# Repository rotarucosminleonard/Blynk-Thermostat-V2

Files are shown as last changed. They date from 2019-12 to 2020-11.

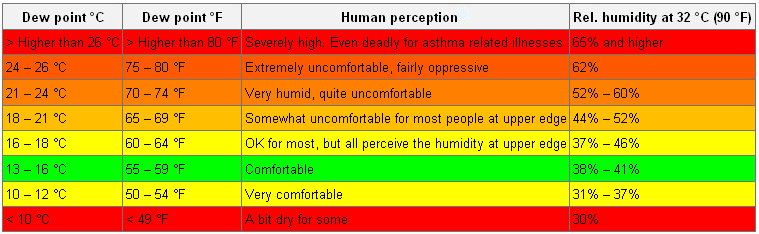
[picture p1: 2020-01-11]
Project files/DewPointComfortRange.jpg

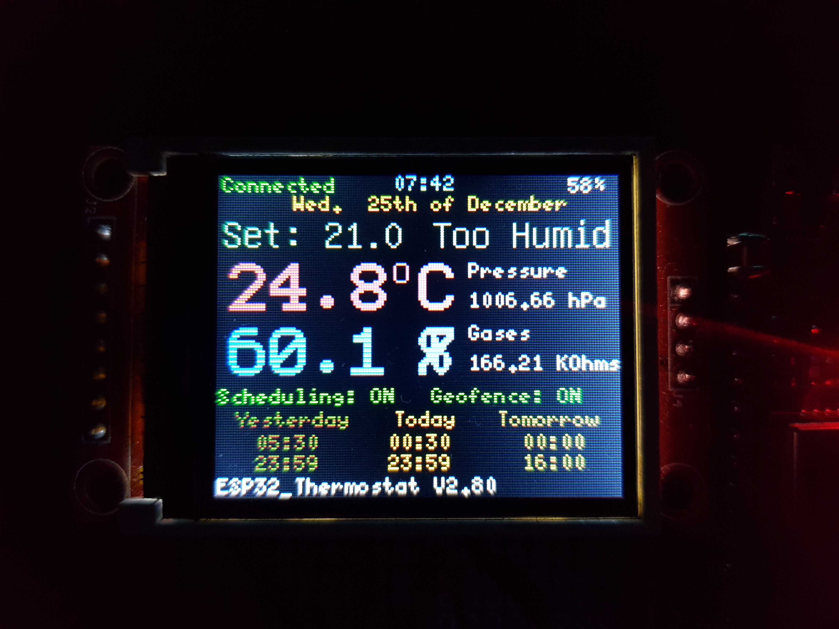
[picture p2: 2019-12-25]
Project files/20191225_074357.jpg

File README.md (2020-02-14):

Warning: This is a work in progress and some of the features are not fully working or not even implemented yet.

The hardware used:
- ESP32 Dev Board
- I2C BME680 for measuring the temp,hum, pressure and air quality - can be easily replaced by the cheaper <a href = "https://www.ebay.co.uk/itm/10DOF-I2C-SPI-MPU9250-BMP280-BME280-Kompass-Barom-for-Arduino-Raspberry-Pi-UK/192137880381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"> BME280(temp,hum,pressure)</a>
- I2C MCP23017
- I2C RTC DS13017z
- SPI ST7735
- <a href ="https://www.ebay.co.uk/itm/Hot-Mini-Wireless-433Mhz-RF-Control-Remote-1527-Learning-Code-Transmitter-Module/232451380539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"> 433 Mhz transmitter</a>
- <a href= "https://www.ebay.co.uk/itm/DC-12V-1-Ch-433MHz-Wireless-Relay-RF-Remote-Control-Switch-Heterodyne-Receiver/292158576954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"> 433 Mhz Relay Module</a> + <a href = "https://www.ebay.co.uk/itm/1-2-5PCS-AC110-220V-to-DC12V-Voltage-Power-Supply-Step-Down-Converter-Module/283386093098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"> Power Module </a>

# Blynk-Thermostat-V2
A smart version of a thermostat that can work and be fully programmed online or offline. It will store the required settings and inputs like temperature setting, operating mode, the time and the time intervals required for scheduling in order to work offline when the connection to the server drops. It will be able to recover it when it's available again. The output command for the heating device can be adjusted for the needs. I am currently using 433mhz modules from eBay for wireless transmission to the heating system and the relay for triggering it. The local time is updated from the server automatically and kept by the RTC module. It can use data from up to remote 3 sensors as temperature reference for heating logic (radiator valves required for this to prevent overheating in some other rooms). 

About the project:
+ The ESP32 works using the Blynk Platform and it displays the data on a LCD colour display (ST7735)  using the UCGLIB library. 
+ The IO pins are extended using the I2c MCP23017 giving the chance to add enough buttons and covering any future hardware improvements. 
+ The offline time kept by an external I2C RTC DS13017z using a library that does not conflict with the Online RTC used by Blynk

Working:
- Scheduling with Geofence Feature
- Heating logic
- Storing the required settings - More tests required
- Timekeeping  - More tests required
- Connection management  - More tests required
- Geofence 
- Wifi Signal
- Local temperature as a refference
- Up to 3 Remote sensors can be used for temperature refference  - More tests required
- Heartbeat for all 3 sensors  - More tests required
- Menu - In progress...

ESP32 (install board)- https://github.com/espressif/arduino-esp32/blob/master/docs/arduino-ide/boards_manager.md

Libraries required:
- Blynk: http://help.blynk.cc/en/articles/512105-how-to-install-blynk-library-for-arduino-ide
- Ucglib: https://github.com/olikraus/ucglib
- Adafruit Unified Sensor: https://github.com/adafruit/Adafruit_Sensor
- Adafruit BME680: https://github.com/adafruit/Adafruit_BME680 ( also recommended BME280) 
- Adafruit MCp23017: https://github.com/adafruit/Adafruit-MCP23017-Arduino-Library
- Arduino Time Library: https://github.com/PaulStoffregen/Time
- Grove - RTC DS1307 : https://github.com/Seeed-Studio/RTC_DS1307

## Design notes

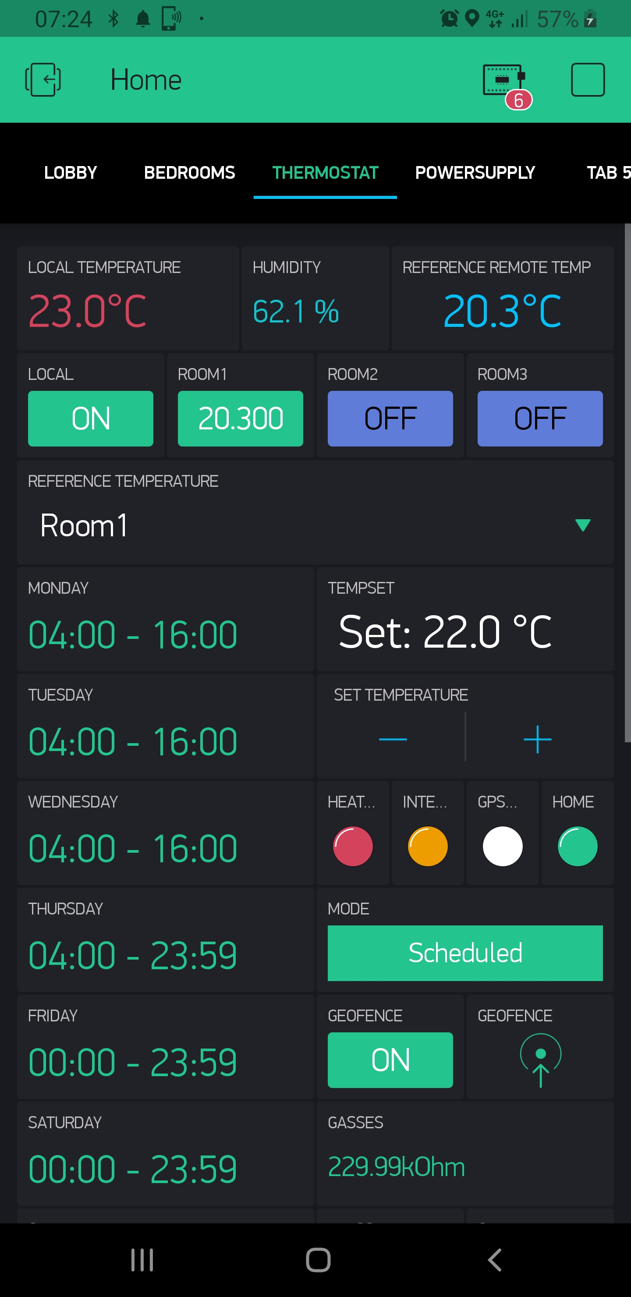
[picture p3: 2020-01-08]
Project files/Screenshot_20200108-072409_Blynk.jpg

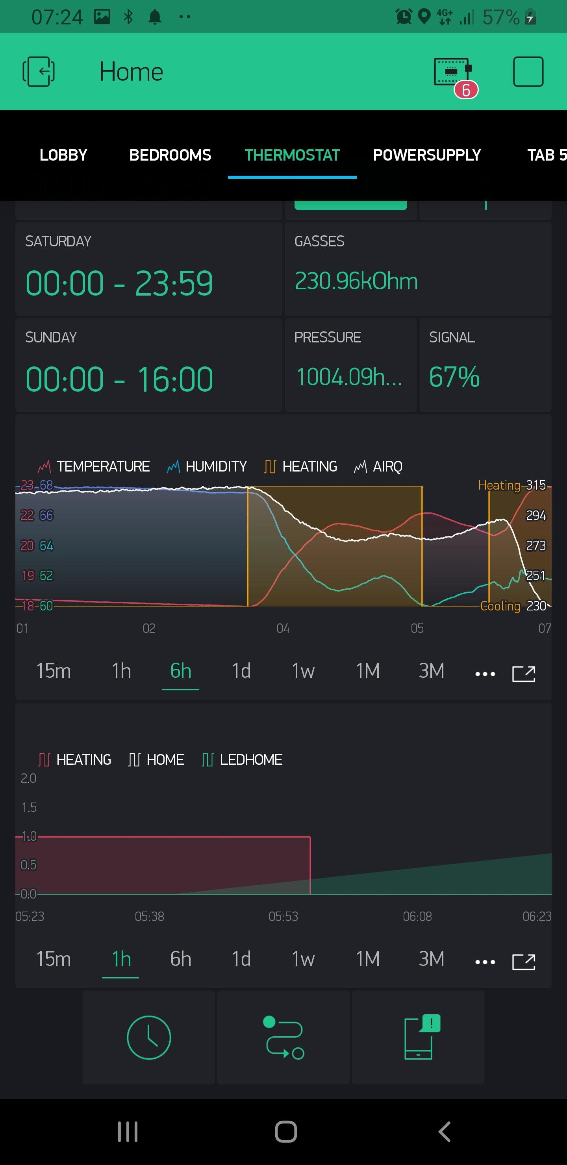
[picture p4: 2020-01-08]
Project files/Screenshot_20200108-072417_Blynk.jpg

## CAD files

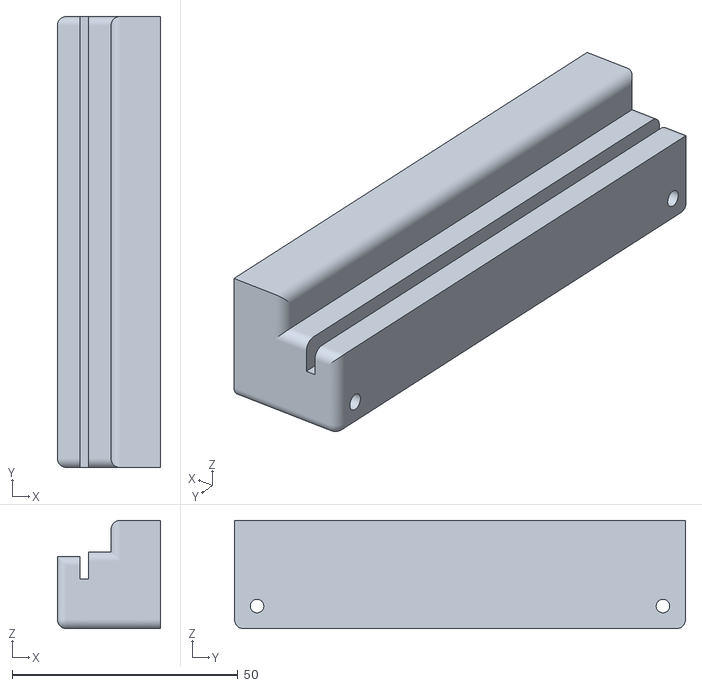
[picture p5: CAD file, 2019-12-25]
Project files/Wal Mount.stl
22.9 x 100.0 x 24.0

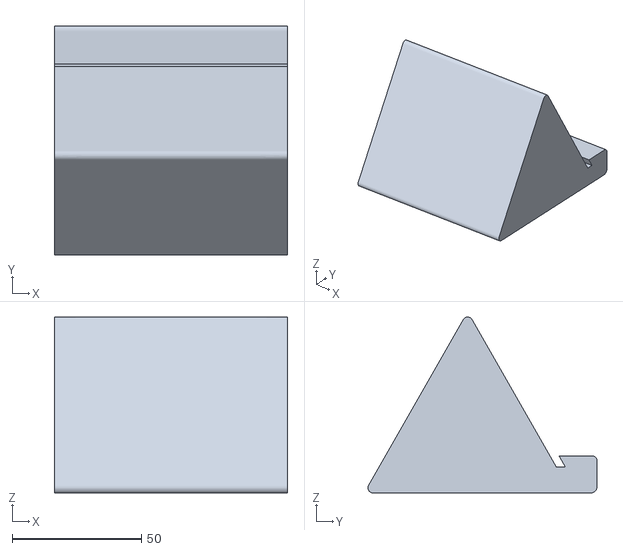
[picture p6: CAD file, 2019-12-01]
Project files/Desk Support.stl
90.0 x 88.6 x 68.0

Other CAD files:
Project files/Wal Mount.ipt

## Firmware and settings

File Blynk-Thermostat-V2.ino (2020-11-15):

/*
  A smarter version of a thermostat that can work and be fully programmed online or offline. It will store the required 
settings and inputs like temperature set, operating mode, the time and the time intervals required for scheduling
in order to work offline when the connection to the server drops. It will be able to recover it when its available again. 
The output command for the heating device can be adjusted for the needs. I am currently using 433mhz modules from ebay 
for wireless transmission to the heating system and the relay for trggering it. The local time is updated from the server 
automatically and kept by the rtc module.
  Features:
  - 
 */


#define NAMEandVERSION "ESP32_Thermostat V2.84"

bool SingleRoomMode = 0; // Set this to 1 if you decide not to use Remote Sensors
float tempDrop = 0.4;    // temperature difference required to start the heating again
float tempOvershoot = 0.2; // temperature difference to stop the heating before reaching the temperature set

#include "config.h" // SSID,PASS, AUTH,serveraddr

//#define BLYNK_DEBUG

#define BLYNK_TIMEOUT_MS  2000  // must be BEFORE BlynkSimpleEsp8266.h doesn't work !!! save value 500
#define BLYNK_HEARTBEAT   30   // must be BEFORE BlynkSimpleEsp8266.h save value is 17s
#define BLYNK_PRINT Serial    

#include <WiFi.h>
#include <WiFiClient.h>
#include <BlynkSimpleEsp32.h>

#include "Ucglib.h"
#include <SPI.h>
#include <Wire.h>
//#include <Adafruit_BMP280.h>
#include <Adafruit_Sensor.h>
#include "Adafruit_BME680.h"

#include "Adafruit_MCP23017.h"
#include <WidgetRTC.h>
#include <EEPROM.h>
//  // each byte of the EEPROM can only hold a value from 0 to 255.

#include "DS1307.h"
DS1307 OfflineRTC;//define a object of DS1307 class

#include <TimeLib.h>
BlynkTimer timer;
WidgetRTC   OnlineRTC;
WidgetTerminal terminal(V1);



#define SDA 21
#define SCL 22           /// I2C pins
Adafruit_MCP23017 mcp;

//Adafruit_BMP280 bmp;
Adafruit_BME680 bme; // I2C

#define SEALEVELPRESSURE_HPA (1013.25)

Ucglib_ST7735_18x128x160_HWSPI ucg(/*cd=*/ 25, /*cs=*/ 26, /*reset=*/ 27); 

// Hardware SPI pins used by the display:
// LED            = 3.3v
// SCK            = 18
// SDA = MOSI     = 23
// A0             = 25
// Reset          = 27
// CS             = 26

// Hardware I2C pins used by the rest of the devices:
// SCL = 22
// SDA = 21

// Pins from the IO extender
#define LED_PIN 2           
#define LEDpin 6
#define LEFTpin 4
bool prevLeftState;
#define UPpin 3
bool prevUpState;
#define DOWNpin 2
bool prevDownState;
#define RIGHTpin 1
bool prevRightState;
#define OKpin 0
bool prevOkState;
#define CANCELpin 5
bool prevCancelState;

int t;

#define RELAYoNpin 33
#define RELAYoFFpin 13

bool theLEDState;
bool leftKey;
bool upKey;
bool downKey;
bool rightKey;
bool okKey;
bool cancelKey;

// These should be generic to all devices, except the air quality 
#define onlineStatusVPin     V0   // used for hardware monitoring 
#define heartbeatVPin        V1   // used for hardware monitoring
#define wifiSignalVPin       V2   // percentage of wifi strenght
#define tempVPin             V3   // realtime temperature value
#define humVPin              V4   // realtime humidity value
#define pressureVPin         V5   // realtime pressure value
#define gassVPin             V6   // realtime gass readings value
#define airQualityVPin       V8   // placeholder for air quality
#define dewPointVPin         V9   // placeholder for air quality

 

// LED widgets used for bynary monitoring
WidgetLED  ledHeatingStatus(V30);
WidgetLED       ledInterval(V31);
WidgetLED     ledGPSAutoOff(V32);
WidgetLED     ledGPSTrigger(V33);

// These are specific to this thermostat

#define tempSetVPin         V10
#define timeInterval1VPin   V21 // Moday
#define timeInterval2VPin   V22 // Tuesday
#define timeInterval3VPin   V23 // Wednesday
#define timeInterval4VPin   V24 // Thursday
#define timeInterval5VPin   V25 // Friday
#define timeInterval6VPin   V26 // Saturday
#define timeInterval7VPin   V27 // Sunday


//#define tempSetControlVPin  V14
#define setModeVPin         V15 // manual vs scheduled interval
#define referenceTempVPin   V16 // the reference remote temperature used by the thermostat
#define geofenceSwitchVPin  V18 // geofence should work on manual or int
#define locationVPin        V20 // Use the mirror instead. It gets received any time it is requested.


//Running on Multiple rooms MODE requires radiator valves
//remote temperature

#define referenceZoneVPin   V17 // temperature from which room
int referenceZone = 1; 

#define room1Vpin V51
#define room2Vpin V52
#define room3Vpin V53

#define EnableRoom1Vpin V54
#define EnableRoom2Vpin V55
#define EnableRoom3Vpin V56
#define EnableLocalVpin V50

bool EnableRoom1 = 0;
bool EnableRoom2 = 0;
bool EnableRoom3 = 0;
bool EnableLocal = 1;

#define HBroom1Vpin V61
#define HBroom2Vpin V62
#define HBroom3Vpin V63

float room1Temp = 99;
float room2Temp = 99;
float room3Temp = 99;

bool HBroom1 = 1;
bool HBroom2 = 1;
bool HBroom3 = 1;

bool room1Status = 1;
bool room2Status = 1;
bool room3Status = 1;


int counter = 0;
signed short int rssi = 0;
signed short int signalQuality = 0;

// menu
int position;
int menu;
int cursorpos;
int value;
bool save;

bool on = 0;
bool online = 0;
bool wifi = 0;
bool server = 0;

int today;
int tomorrow;
int yesterday;

//Widget Variables to Use
int StartHour = 0;
int StopHour = 0;
int StartMinute = 0;
int StopMinute = 0;
bool StartTime = 0;
bool StopTime = 0;
int StartHourAddress = 6;
int StopHourAddress = 7;
int StartMinuteAddress = 8;
int StopMinuteAddress = 9;

int Hour = 0;
int Minute = 0;
int beforearrival = 0;
bool preheating = 0; 

//Monday Widged Variables to use
int StartHour1 = 0;
int StopHour1 = 0;
int StartMinute1 = 0;
int StopMinute1 = 0;
bool StartTime1 = 0;
bool StopTime1 = 0;
int StartHour1Address = 10;
int StopHour1Address = 11;
int StartMinute1Address = 12;
int StopMinute1Address = 13;

//Tuesday Widged Variables to use
int StartHour2 = 0;
int StopHour2 = 0;
int StartMinute2 = 0;
int StopMinute2 = 0;
bool StartTime2 = 0;
bool StopTime2 = 0;
int StartHour2Address = 20;
int StopHour2Address = 21;
int StartMinute2Address = 22;
int StopMinute2Address = 23;

//Wednesday  Widged Variables to use
int StartHour3 = 0;
int StopHour3 = 0;
int StartMinute3 = 0;
int StopMinute3 = 0;
bool StartTime3 = 0;
bool StopTime3 = 0;
int StartHour3Address = 30;
int StopHour3Address = 31;
int StartMinute3Address = 32;
int StopMinute3Address = 33;

//Thursday Widged Variables to use
int StartHour4 = 0;
int StopHour4 = 0;
int StartMinute4 = 0;
int StopMinute4 = 0;
bool StartTime4 = 0;
bool StopTime4 = 0;
int StartHour4Address = 40;
int StopHour4Address = 41;
int StartMinute4Address = 42;
int StopMinute4Address = 43;

//Friday Widged Variables to use
int StartHour5 = 0;
int StopHour5 = 0;
int StartMinute5 = 0;
int StopMinute5 = 0;
bool StartTime5 = 0;
bool StopTime5 = 0;
int StartHour5Address = 50;
int StopHour5Address = 51;
int StartMinute5Address = 52;
int StopMinute5Address = 53;

//Saturday Widged Variables to use
int StartHour6 = 0;
int StopHour6 = 0;
int StartMinute6 = 0;
int StopMinute6 = 0;
bool StartTime6 = 0;
bool StopTime6 = 0;
int StartHour6Address = 60;
int StopHour6Address = 61;
int StartMinute6Address = 62;
int StopMinute6Address = 63;

//Sunday Widged Variables to use
int StartHour7 = 0;
int StopHour7 = 0;
int StartMinute7 = 0;
int StopMinute7 = 0;
bool StartTime7 = 0;
bool StopTime7 = 0;
int StartHour7Address = 70;
int StopHour7Address = 71;
int StartMinute7Address = 72;
int StopMinute7Address = 73;

bool Mo = 0;
bool Tu = 0;
bool We = 0;
bool Th = 0;
bool Fr = 0;
bool Sa = 0;
bool Su = 0;


bool onlinetimechk; // wont let the time synk unless the online time got updated

float temp = 0;
float h = 0;
float p = 0;
float g = 0;
float a = 0;
float dewPoint;
float heatIndex;
float cr;
float LastTemp;
float PrevTempset;

bool scheduled;
bool GPSTrigger;
bool GPSAutoOff;

float tempset = 0.0; // realtime temperature
float referenceTemp = 0;
float bottomTreshold;
float topThreshold;

// EEPROM adreses
int tempsetaddress = 0;
int scheduledaddress = 1;
int GPSAutoOffaddress = 2;

bool HEATING;
bool STOPPED;
bool interval;


void setup() {

  pinMode(RELAYoNpin, OUTPUT); 
  pinMode(RELAYoFFpin, OUTPUT); 
  digitalWrite(RELAYoNpin, HIGH);
  digitalWrite(RELAYoFFpin, HIGH);
  Serial.begin(115200);
  Serial.println();

  EEPROM.begin(512);
  tempset = EEPROM.read(tempsetaddress);
  scheduled = EEPROM.read(scheduledaddress);


  EEPROM.write(StopHour1Address, StopHour1);  
  EEPROM.write(StopMinute1Address, StopMinute1);  

  
  StartHour1 = EEPROM.read(StartHour1Address);
  StartHour2 = EEPROM.read(StartHour2Address);
  StartHour3 = EEPROM.read(StartHour3Address);
  StartHour4 = EEPROM.read(StartHour4Address);
  StartHour5 = EEPROM.read(StartHour5Address);
  StartHour6 = EEPROM.read(StartHour6Address);
  StartHour7 = EEPROM.read(StartHour7Address); 
   
  StartMinute1 = EEPROM.read(StartMinute1Address);
  StartMinute2 = EEPROM.read(StartMinute2Address);
  StartMinute3 = EEPROM.read(StartMinute3Address);
  StartMinute4 = EEPROM.read(StartMinute4Address);
  StartMinute5 = EEPROM.read(StartMinute5Address);
  StartMinute6 = EEPROM.read(StartMinute6Address);
  StartMinute7 = EEPROM.read(StartMinute7Address); 

  StopHour1 = EEPROM.read(StopHour1Address);
  StopHour2 = EEPROM.read(StopHour2Address);
  StopHour3 = EEPROM.read(StopHour3Address);
  StopHour4 = EEPROM.read(StopHour4Address);
  StopHour5 = EEPROM.read(StopHour5Address);
  StopHour6 = EEPROM.read(StopHour6Address);
  StopHour7 = EEPROM.read(StopHour7Address); 

  StopMinute1 = EEPROM.read(StopMinute1Address);
  StopMinute2 = EEPROM.read(StopMinute2Address);
  StopMinute3 = EEPROM.read(StopMinute3Address);
  StopMinute4 = EEPROM.read(StopMinute4Address);
  StopMinute5 = EEPROM.read(StopMinute5Address);
  StopMinute6 = EEPROM.read(StopMinute6Address);
  StopMinute7 = EEPROM.read(StopMinute7Address); 
  

delay(100);
  ucg.begin(UCG_FONT_MODE_TRANSPARENT);
  ucg.clearScreen();
  //ucg.undoRotate(); break;
  ucg.setRotate90();  //landscape,pins on the left
  //ucg.setRotate180(); break;
  //ucg.setRotate270(); break;

  WiFi.setHostname(NAMEandVERSION);
  WiFi.mode(WIFI_STA);
  //WiFi.config(arduino_ip, gateway_ip, subnet_mask);
  //Blynk.config(auth, IPAddress(192,168,0,3), port);  // I am using the local Server
  Blynk.config(auth, serveraddr, port);  // I am using the local Server

  Wire.begin(SDA,SCL);
  mcp.begin();      // use default address 0
  //mcp.begin(0x20);      // use custom address
  
  OfflineRTC.begin();
  //delay(1000);
  OfflineTime();
  
//  OfflineRTC.fillByYMD(2013,1,19);//Jan 19,2013
//  OfflineRTC.fillByHMS(15,28,30);//15:28 30"
//  OfflineRTC.fillDayOfWeek(SAT);//Saturday
//  OfflineRTC.setTime();//write time to the RTC chip


  // Only used once, then disabled - Setting the clock
//   rtc.set(0, 40, 18, 2, 6, 8, 19);
  // RTCLib::set(byte second, byte minute, byte hour, byte dayOfWeek, byte dayOfMonth, byte month, byte year)
  
  pinMode(LED_PIN, OUTPUT);
  mcp.pinMode(LEDpin, OUTPUT);
  mcp.pinMode(LEFTpin, INPUT);
  mcp.pinMode(UPpin, INPUT);
  mcp.pinMode(DOWNpin, INPUT);
  mcp.pinMode(RIGHTpin, INPUT);
  mcp.pinMode(OKpin, INPUT);
  mcp.pinMode(CANCELpin, INPUT);
  /* Default settings from datasheet. */
//  bmp.setSampling(Adafruit_BMP280::MODE_NORMAL,     /* Operating Mode. */
//                  Adafruit_BMP280::SAMPLING_X4,     /* Temp. oversampling */
//                  Adafruit_BMP280::SAMPLING_X16,    /* Pressure oversampling */
//                  Adafruit_BMP280::FILTER_X16,      /* Filtering. */
//                  Adafruit_BMP280::STANDBY_MS_500); /* Standby time. */
//                  
//  Serial.println(F("BMP280 test"));
//  if (!bmp.begin(0x76)) {
//    Serial.println(F("Could not find a valid BMP280 sensor, check wiring!"));
//    //while (1);
//  }

  Serial.println(F("BME680 async test"));

  if (!bme.begin()) {
    Serial.println(F("Could not find a valid BME680 sensor, check wiring!"));
    while (1);
  }

  // Set up oversampling and filter initialization
  bme.setTemperatureOversampling(BME680_OS_8X);
  bme.setHumidityOversampling(BME680_OS_4X);
  bme.setPressureOversampling(BME680_OS_4X);
  bme.setIIRFilterSize(BME680_FILTER_SIZE_3);
  bme.setGasHeater(320, 150); // 320*C for 150 ms
  ReadBME680(); 
  CheckConnection();// It needs to run first to initiate the connection.Same function works for checking the connection!
  timer.setInterval(60000L, CheckConnection); 
  //  timer.setInterval(1000L, myTimerEvent);    
  timer.setInterval(10100L, ReadBME680);
  timer.setInterval(5000L, BlinkTheLed);  
  timer.setInterval(4000L, mainDisplay);     
  timer.setInterval(100000L,  OfflineTime);
  timer.setInterval(100000L,  OnlineTime);
  timer.setInterval(8000L, PeriodicSync);
  timer.setInterval(20000L, HeatingLogic);
  timer.setInterval(60000L, RemoteSensorsCheck);
  //timer.setInterval(60002L, tempStability);
}

void loop() {
  if(Blynk.connected()){
    Blynk.run();
  }
  timer.run();
  keyboard();
}


BLYNK_CONNECTED() {
  OnlineRTC.begin();
  Serial.println("Got connection to the server. Doing some sync...");
  Blynk.virtualWrite(tempSetVPin, tempset);// update the local tempset TO server
  //Blynk.syncVirtual(timeInterval1VPin);
  Blynk.syncVirtual(geofenceSwitchVPin);
  Blynk.syncVirtual(locationVPin);
  Blynk.syncVirtual(setModeVPin);
  Blynk.syncVirtual(referenceZoneVPin); // Check the refference temperature settings
  Blynk.syncVirtual(EnableLocalVpin);
  Blynk.syncVirtual(EnableRoom1Vpin);
  Blynk.syncVirtual(EnableRoom2Vpin);
  Blynk.syncVirtual(EnableRoom3Vpin);
  Blynk.syncVirtual(referenceZoneVPin);
    // Synchronize time on connection
//  OfflineTime();
//  delay(100);
//  OfflineTime();
//  delay(100);
  OfflineTime();
  OnlineTime();
  syncTheTime();
  Blynk.syncVirtual(timeInterval1VPin);
  Blynk.syncVirtual(timeInterval2VPin);
  Blynk.syncVirtual(timeInterval3VPin);
  Blynk.syncVirtual(timeInterval4VPin);
  Blynk.syncVirtual(timeInterval5VPin);
  Blynk.syncVirtual(timeInterval6VPin);
  Blynk.syncVirtual(timeInterval7VPin);
}

void PeriodicSync()
{
  if(Blynk.connected())
  {
    Serial.println("Periodic Sync...");
    // Push to the server
    Blynk.virtualWrite(tempVPin, temp);
    Blynk.virtualWrite(humVPin, h);
    Blynk.virtualWrite(dewPointVPin, dewPoint);
    Blynk.virtualWrite(pressureVPin, p);
    Blynk.virtualWrite(gassVPin, g);
     
    Blynk.virtualWrite(tempSetVPin, tempset);
    
//    Blynk.virtualWrite(tempSetVPin, tempset); //only after the local storage in the memory
    Blynk.virtualWrite(wifiSignalVPin, signalQuality);
    Blynk.virtualWrite(referenceTempVPin, referenceTemp);// reference temperature
    // Get from the server
//    Blynk.syncVirtual(timeInterval1VPin);// scheduled interval 1
//    Blynk.syncVirtual(timeInterval2VPin);// scheduled interval 2 
//    Blynk.syncVirtual(timeInterval3VPin);// scheduled interval 3  
  }
}


void BlinkTheLed()
{
//  Serial.println("The LED");
  if (theLEDState == 1) {
    // btnState is used to avoid sequential toggles
      digitalWrite(LED_PIN, LOW);
      theLEDState = 0;
    }
  else {
    digitalWrite(LED_PIN, HIGH);
    theLEDState = 1;
  }
}


void signalStrength()
{
  if (WiFi.status() != WL_CONNECTED) { 
    Serial.println("No WiFi connection yet!");
  } 
  // if you are connected, print out info about the connection:
  else {
   // print the received signal strength:
  rssi = WiFi.RSSI();
  Serial.print("RSSI:");
  Serial.println(rssi); // -90 the worst ~ -30 the best
  signalQuality = ((1 - ( (-30) - float(rssi) ) / 70) * 100) ;
  Serial.print("Signal Quality: ");
  Serial.println(signalQuality);
  }  
}


void ReadBME680() 
{
  if (! bme.performReading()) {
    Serial.println("Failed to perform reading :(");
    return;
  }

  temp = (bme.temperature);
  p = (bme.pressure / 100.0);
  h = (bme.humidity);
  g = (bme.gas_resistance / 1000.0);
  a = (bme.readAltitude(SEALEVELPRESSURE_HPA));
  dewPoint =  (temp - (14.55 + 0.114 * temp) * (1 - (0.01 * h)) - pow(((2.5 + 0.007 * temp) * (1 - (0.01 * h))),3) - (15.9 + 0.117 * temp) * pow((1 - (0.01 * h)), 14));
  Serial.println("DewPoint=" + String(dewPoint));
  
}

void tempStability()
{
  float tempDif = 0;
  tempDif = temp - LastTemp;
  LastTemp = temp;
  Serial.println("Tempdif = " + String(tempDif));
  if (tempDif >= 1) {
    Serial.print("Heating to fast! Temperature = " + String(temp));
    Blynk.notify("Heating to fast! Temperature = " + String(temp));
    Blynk.email("rotarucosminleonard@gmail.com", "Temperature Alert!", "Temperature is increasing to fast at home!");
  }
  else if (tempDif <= -0.3)
  {
    Serial.print("The windows are open. Stop heating for now.");
    Blynk.notify("The windows are open. Stop heating for now.");
    PrevTempset = tempset;
    tempset = 10;
  }
  if (tempset == 10){
    if (tempDif <= 0.2 || tempDif > -0.3 ){
      Serial.print("The windows are Closed now. Start heating again.");
      Blynk.notify("The windows are Closed now. Start heating again.");
      tempset = PrevTempset;
    }
  }

}

void RemoteSensorsCheck() 
{
  if (HBroom1 == 1)
  {
    HBroom1 = 0;
    Blynk.setProperty(EnableRoom1Vpin, "onBackColor", "#23C48E"); //Green Background color
    Blynk.setProperty(EnableRoom1Vpin, "onLabel", room1Temp); // Post temperature as label
    // Good To USE
    room1Status = 1;
  }
  else 
  {
    Serial.println("The device from room 1 is OFFLINE");
    Blynk.setProperty(EnableRoom1Vpin, "onBackColor", "#D3435C"); // Red Background color
    // NOT Good To USE
    room1Status = 0;
    room1Temp = 99;
  }

  if (HBroom2 == 1)
  {
    HBroom2 = 0;
    Blynk.setProperty(EnableRoom2Vpin, "onBackColor", "#23C48E"); //Green Background color
    Blynk.setProperty(EnableRoom2Vpin, "onLabel", room2Temp); // Post temperature as label
    // Good To USE
    room2Status = 1;
  }
  else 
  {
    Serial.println("The device from room 2 is OFFLINE");
    Blynk.setProperty(EnableRoom2Vpin, "onBackColor", "#D3435C"); // Red Background color
    // NOT Good To USE
    room2Status = 0;
    room2Temp = 99;
  }

  if (HBroom3 == 1)
  {
    HBroom3 = 0;
    Blynk.setProperty(EnableRoom3Vpin, "onBackColor", "#23C48E"); //Green Background color
    Blynk.setProperty(EnableRoom3Vpin, "onLabel", room3Temp); // Post temperature as label
    // Good To USE
    room3Status = 1;
  }
  else 
  {
    Serial.println("The device from room 3 is OFFLINE");
    Blynk.setProperty(EnableRoom3Vpin, "onBackColor", "#D3435C"); // Red Background color
    // NOT Good To USE
    room3Status = 0;
    room3Temp = 99;
  }
  
}

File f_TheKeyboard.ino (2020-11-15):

void keyboard()
{

  leftKey = mcp.digitalRead(LEFTpin);
  upKey = mcp.digitalRead(UPpin);
  downKey = mcp.digitalRead(DOWNpin);
  rightKey = mcp.digitalRead(RIGHTpin);
  okKey = mcp.digitalRead(OKpin);
  cancelKey = mcp.digitalRead(CANCELpin);


  upKey = mcp.digitalRead(UPpin);
  if (upKey != prevUpState) {
    if (upKey == LOW) {
      if (menu == 0) {
        tempset=tempset+0.5;
        EEPROM.write(tempsetaddress, tempset);
        EEPROM.commit();
        if(Blynk.connected())
        {
          Blynk.virtualWrite(tempSetVPin, tempset);    
        }
        Serial.println("Increased tempset: ");
        Serial.println(tempset);
        delay(50);  
        mainDisplay();  
      }
      else {
        cursorpos ++;
        delay(50);        
      }

    }
    prevUpState = upKey;
  }


  downKey = mcp.digitalRead(DOWNpin);
  if (downKey != prevDownState) {
    if (downKey == LOW) {
      if (menu == 0) {
        tempset=tempset-0.5;
        EEPROM.write(tempsetaddress, tempset);
        EEPROM.commit();
        if(Blynk.connected())
        {
          Blynk.virtualWrite(tempSetVPin, tempset);  
        }
        Serial.println("Decreased tempset: ");  
        Serial.println(tempset);
        delay(50);    
        mainDisplay();      
      }
      else {
        cursorpos --;
        delay(50);      
      }

    }
    prevDownState = downKey;
  }


  leftKey = mcp.digitalRead(LEFTpin);
  if (leftKey != prevLeftState) {
    if (leftKey == LOW) {
      if (menu == 0){
        if (scheduled == 1){
          scheduled = 0;
          EEPROM.write(scheduledaddress, scheduled);
          EEPROM.commit();            
        }
        else {
          scheduled = 1;
          EEPROM.write(scheduledaddress, scheduled);
          EEPROM.commit();     
        }
      }
      else {
        value--;        
      }

    }
    prevLeftState = leftKey;
  }

  rightKey = mcp.digitalRead(RIGHTpin);
  if (rightKey != prevRightState) {
    if (rightKey == LOW) {
      if (menu == 0){
        if (scheduled == 1){
          scheduled = 0;
          EEPROM.write(scheduledaddress, scheduled);
          EEPROM.commit();            
        }
        else {
          scheduled = 1;
          EEPROM.write(scheduledaddress, scheduled);
          EEPROM.commit();     
        }
      }
      else {
        value++;        
      }
    }
    prevRightState = rightKey;
  }



  okKey = mcp.digitalRead(OKpin);
  if (okKey != prevOkState) {
    if (okKey == LOW) {
      if (menu == 0){
        menu = 1;        
      }
      else {
        // save function
        //selectt=1;
      }

    }
    prevOkState = okKey;
    mainDisplay();
  }

  cancelKey = mcp.digitalRead(CANCELpin);
  if (cancelKey != prevCancelState) {
    if (cancelKey == LOW) {
      if (menu >= 0){
        // back up a menu  
        menu = menu-1;
      }
    ucg.clearScreen();
    mainDisplay();
    }
    prevCancelState = cancelKey;

  }
  
}

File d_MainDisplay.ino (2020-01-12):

void mainDisplay()
{
  if (menu == 0){
    ucg.setColor(0, 255, 255, 255);    // use white as main color for the font
    ucg.setFontMode(UCG_FONT_MODE_SOLID);
    ucg.setFont(ucg_font_5x8_mr);
    if (online == 1)
    {
      ucg.setFont(ucg_font_5x8_mr);
      ucg.setColor(0,255,0); // green
      ucg.setPrintPos(2,7);
      ucg.print("Connected    ");
      signalStrength();
      ucg.setColor(255, 255, 255); 
      ucg.setPrintPos(140, 7); //160/128
      ucg.print(signalQuality);  
      ucg.print("%");       
    }
    else if (wifi == 0)
    {
      ucg.setFont(ucg_font_5x8_mr);
      ucg.setColor(255,0,0);
      ucg.setPrintPos(2,6);
      ucg.print("Wifi Issue");     
      ucg.setColor(255, 0, 0); 
      ucg.setPrintPos(140, 7); //160/128
      ucg.print("0%");      
    }
    else if (wifi == 1 && server == 0)
    {
      ucg.setFont(ucg_font_5x8_mr);
      ucg.setColor(255,0,0);
      ucg.setPrintPos(2,6);
      ucg.print("Server Issue"); 
      signalStrength();
      ucg.setColor(255, 255, 255); 
      ucg.setPrintPos(140, 7); //160/128
      ucg.print(signalQuality);
      ucg.print("%");      
    }
    
      ucg.setFont(ucg_font_5x8_mr);
      ucg.setColor(50, 180, 255);
      ucg.setPrintPos(70,6);
    if ((OfflineRTC.hour) < 10)    {
      ucg.print( "0"+ String(OfflineRTC.hour, DEC));
    }
    else {
      ucg.print(String(OfflineRTC.hour, DEC));
    }
      
    ucg.print(":");
    if ((OfflineRTC.minute) < 10)    {
      ucg.print( "0"+ String(OfflineRTC.minute, DEC) + String("  "));
    }
    else {
      ucg.print(String(OfflineRTC.minute, DEC) + String("  "));
    }
      
    ucg.setFont(ucg_font_5x8_mr);
    ucg.setColor(255, 200, 0);
    ucg.setPrintPos(30,14);
    switch (OfflineRTC.dayOfWeek)// Friendly printout the weekday
    {
      case MON:
        ucg.print("Mon. ");
        break;
      case TUE:
        ucg.print("Tue. ");
        break;
      case WED:
        ucg.print("Wed. ");
        break;
      case THU:
        ucg.print("Thu. ");
        break;
      case FRI:
        ucg.print("Fri. ");
        break;
      case SAT:
        ucg.print("Sat. ");
        break;
      case SUN:
        ucg.print("Sun. ");
        break;
    }
      
    if ((OfflineRTC.dayOfMonth) == 1)
    {
      ucg.print(" " + String(OfflineRTC.dayOfMonth)+"st of " );   
    }
    else if ((OfflineRTC.dayOfMonth) == 2)
    {
      ucg.print(" " + String(OfflineRTC.dayOfMonth)+"nd of " );   
    }
    else if ((OfflineRTC.dayOfMonth) == 3)
    {
      ucg.print(" " + String(OfflineRTC.dayOfMonth)+"rd of " );   
    }
    else if ((OfflineRTC.dayOfMonth) > 3 )
    {
      ucg.print(" " + String(OfflineRTC.dayOfMonth)+"th of " );      
    }
      
    switch (OfflineRTC.month)// Friendly printout the month
    {
      case 1:
        ucg.print("January");
        break;
      case 2:
        ucg.print("February");
        break;
      case 3:
        ucg.print("March    ");
        break;
      case 4:
        ucg.print("April    ");
        break;
      case 5:
        ucg.print("May      ");
        break;
      case 6:
        ucg.print("June     ");
        break;
      case 7:
        ucg.print("July     ");
        break;
      case 8:
        ucg.print("August   ");
        break;
      case 9:
        ucg.print("September");
        break;
      case 10:
        ucg.print("October  ");
        break;
      case 11:
        ucg.print("November ");
        break;
      case 12:
        ucg.print("December ");
        break;
    }


    ucg.setFont(ucg_font_unifont_mr);
    ucg.setColor(100, 255, 100);
    ucg.setPrintPos(2,29);
    ucg.print("Set: "); ucg.print(tempset,1);
    ucg.setPrintPos(85,29);
    if (h > 55)
    {
      ucg.print("Too Humid!");  //  Comfort Level      
    }
    else if (h < 30)
    {
      ucg.print("Too Dry!  ");  //  Comfort Level      
    }
    else if (h > 29 && h<55)
    {
      ucg.print("Comfy!    ");  //  Comfort Level      
    }
  
    ucg.setFont(ucg_font_profont29_mr);
    ucg.setColor(255, 55, 55);
    if (temp >= 10)
    {
      ucg.setPrintPos(5,54);    
    }
    else if (temp<10)
    {
    ucg.setPrintPos(21,54);   
    }
    ucg.print(temp,1);ucg.setFont(ucg_font_unifont_mr);ucg.setPrintPos(69,43);ucg.print("o");ucg.setPrintPos(80,54);ucg.setFont(ucg_font_profont29_mr);ucg.print("C");  //  Temperature
    ucg.setFont(ucg_font_profont29_mr);
    ucg.setColor(45, 170, 255);
    
    if (h >=10)
    {
      ucg.setPrintPos(5,80);
    }
    else 
    {
      ucg.setPrintPos(21,80);
    }
    ucg.print(h,1);ucg.setPrintPos(80,80);ucg.print("%");  //  Humidity
  
    ucg.setColor(255, 255, 255);
    ucg.setPrintPos(100,41);
    ucg.setFont(ucg_font_5x8_mr);
    ucg.print("Pressure");
    ucg.setPrintPos(100,53);
    ucg.print(p + String(" hPa"));
      
    ucg.setPrintPos(100,66);
    if (dewPoint>26 || dewPoint < 10){
      ucg.setColor(255, 0, 0);
    }
    else if (dewPoint >= 21 && dewPoint < 26){
      ucg.setColor(153, 76, 0); 
    }
    else if (dewPoint >= 18 && dewPoint < 21){
      ucg.setColor(255, 153, 51);
    }
    else if (dewPoint >= 16 && dewPoint < 18){
      ucg.setColor(255, 255, 60);
    }
    else if (dewPoint >= 13 && dewPoint < 16){
      ucg.setColor(0, 255, 0);
    }
    else if (dewPoint >= 10 && dewPoint < 13){
      ucg.setColor(255, 255, 20);
    }
    ucg.setFont(ucg_font_5x8_mr);
    ucg.print("DewPoint");
    ucg.setPrintPos(100,78);
    ucg.print(dewPoint + String(" C   ") );

    if (scheduled == 1)
    {
      ucg.setFont(ucg_font_5x8_mr);
      ucg.setPrintPos(1,91); 
      if (interval == 1) {
        ucg.setColor(0,255,0);  
        ucg.print("Scheduling: ON ");            
      }
      else {
        ucg.setColor(255,0,0);  
        ucg.print("Scheduling: ON ");               
      }
    }
    else if (scheduled == 0)
    {
      ucg.setFont(ucg_font_5x8_mr);
      ucg.setPrintPos(1,91);
      ucg.setColor(255, 200, 0);  
      ucg.print("Scheduling: OFF");          
    }

    if (GPSAutoOff == 1){
      if (GPSTrigger == 1) {
        ucg.setFont(ucg_font_5x8_mr);
        ucg.setPrintPos(85,91);
        ucg.setColor(0,255,0);  
        ucg.print("Geofence: ON ");
      }
      else {
        ucg.setFont(ucg_font_5x8_mr);
        ucg.setPrintPos(85,91);
        ucg.setColor(255,0,0);  
        ucg.print("Geofence: ON ");                   
      }
    }
    else if (GPSAutoOff == 0){
      ucg.setFont(ucg_font_5x8_mr);
      ucg.setPrintPos(85,91);
      ucg.setColor(255, 200, 0);
      ucg.print("Geofence: OFF");    
    }



    // The days Scheduling: Yesterday
    
    ucg.setFont(ucg_font_5x8_mr);
    ucg.setPrintPos(8,100);
    ucg.setColor(100, 100, 0);  
    ucg.print("Yesterday"); 

    ucg.setFont(ucg_font_5x8_mr);
    ucg.setPrintPos(16,109);
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

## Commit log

2019-12-01 Fixed Scheduling
    Fixed Scheduling
    Fixed some display messages
    [Desk Support.stl]
2019-12-08 Various updates
    - Renamed the Main file
    - Fix for Time Synk
    - Fix for Geofence
    - Fix for EEPROM data storing
    [Blynk-ESP32_Thermostat.ino, b_BLYNK_WRITE.ino, c_Check_Interval.ino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]
2019-12-10 Included EAGLE schematic
    All modules added, no connections yet
    Not complete
    [Eagle Schematic.sch]
2019-12-10 Minor uptades
    Wifi and server Updates on a different file
    Progress on the new Scheduling logic
    [Desk Support.stl, Eagle Schematic.sch]
2019-12-14 Scheduling Fix
    -Workign Scheduling with different hour interval for each day
    -Display prints
    Renamed the main code file for easier open on arduino compiler
    [Blynk-Thermostat-V2.ino, b_BLYNK_WRITE.ino, c_Check_Interval.ino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]
2019-12-25 Simple Wall Mounts models added
    STL and IPL files
    [Wal Mount.ipt, Wal Mount.stl]
2019-12-25 Updated schematic
    - Basic description of the connections
2019-12-26 Temperature Compare Improvement
    Updated the temperature comparison logic for improved comfort and reduced temperature overshoot
    [Blynk-Thermostat-V2.ino, d_MainDisplay.ino, g_ThermostatLogic.ino]
2020-01-08 Added New Feature
    - The thermostat can use now remote temperature from up to 3 remote sensors.
    - Heartbeat check for all 3 sensors
    - Offline mode but fixed
    [Blynk-Thermostat-V2.ino, b_BLYNK_WRITE.ino, d_MainDisplay.ino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]
2020-01-11 Minop Updates
    - Temporary solution for the "Selected Rooms" reference temperature
    - Added dew point computing
    - Replaced gases with dew point on the display
    [Blynk-Thermostat-V2.ino, d_MainDisplay.ino, g_ThermostatLogic.ino]
2020-01-12 Fixed Multiple Rooms Mode logic
    - Fixed the algorithms for Multiple Rooms Mode
    - Fixed some typos
    - Increased the timeout
    [Blynk-Thermostat-V2.ino, b_BLYNK_WRITE.ino, c_Check_Interval.ino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]
2020-11-16 time interval fix
    fixed the time interval where the time inteval ends the same day it begins.
    [c_Check_Interval.ino]
